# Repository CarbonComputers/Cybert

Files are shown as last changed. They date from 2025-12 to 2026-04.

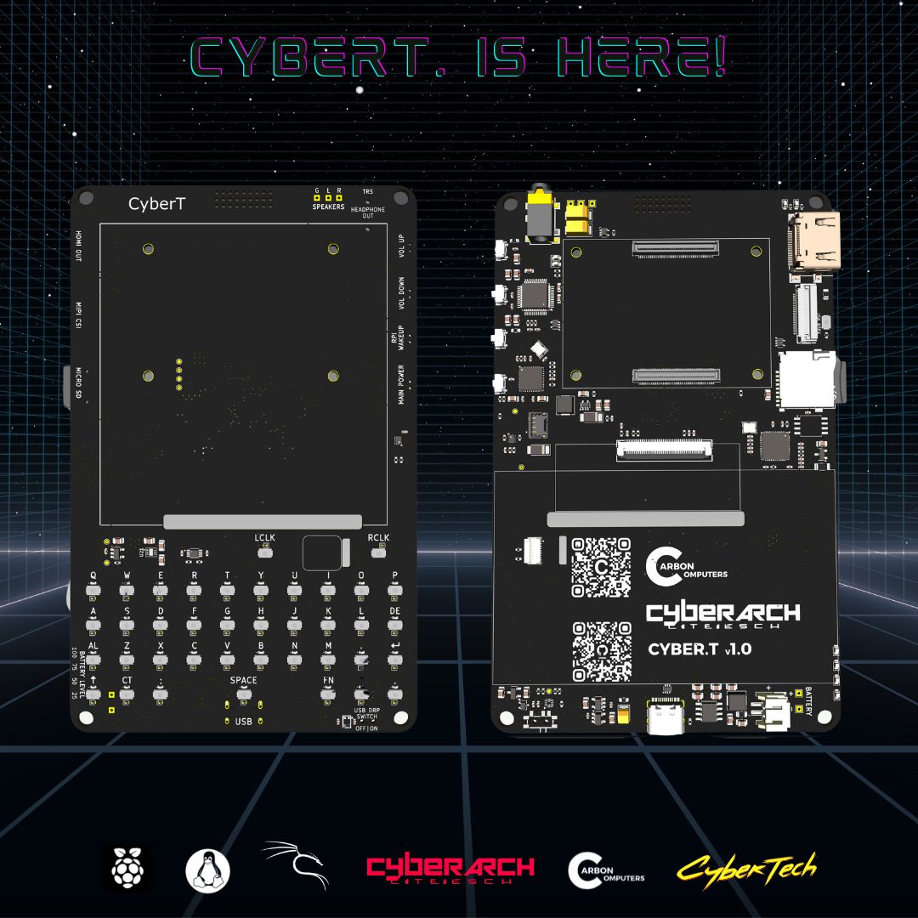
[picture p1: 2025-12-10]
Hardware/Renders/3.jpg

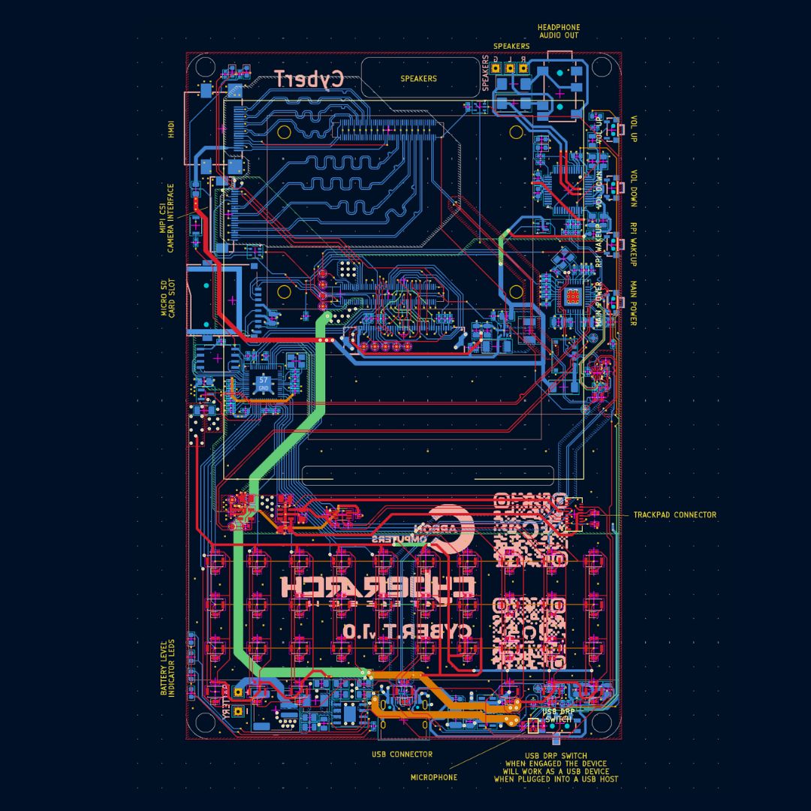
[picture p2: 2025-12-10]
Hardware/Renders/4.jpg

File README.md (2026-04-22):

# Cybert — Raspberry Pi CM5 Handheld Terminal

Order at:
[CarbonComputers.us]
(https://carboncomputers.us/products/cybert-raspberry-pi-cm5-terminal)

Cybert is a compact, modular handheld terminal built around the Raspberry Pi Compute Module 5 (CM5).  
It’s designed for makers, pentesters, IT professionals, students — anyone who needs portable Linux power in a small, customizable footprint.

---

## ⚙️ Features

- **Modular Raspberry Pi CM5 support** — compatible with 4GB, 8GB, or 16GB CM5 boards.  
- **Compact form factor** — optimized for portability while retaining full functionality.  
- **Customizable I/O & expansion** — USB, display, storage, and optional modules (M.2, LoRa, etc.).  
- **Display support** — compatible with TFT/IPS displays (e.g. 3.95" 720×720 or other supported models).  
- **Power & battery** — internal LiPo battery support (varies by configuration).  
- **Active cooler compatible** — supports low-profile cooling solutions for stable performance.  
- **MicroSD / Storage flexibility** — ability to swap OS or storage via microSD, with optional SSD/M.2 expandability.  
- **Open for customization** — intended as a platform for DIY, tinkering, and custom builds.

---

## 📦 What’s Included (Base / Barebones Kit)

Depending on the version you choose, the kit may include:  
- Enclosure (case)  
- Compatible display mount and instructions for supported display  
- Internal wiring/connectors  
- USB port layout & headers  
- Battery compartment and wiring for battery connection  
- PCB / carrier board for CM5 

> ⚠️ Note: If you purchase the *barebones* variant — the CM5 board, storage media, and optional cooler are **not included** and must be provided separately by the user.

---

## 🔧 Recommended Components & Compatibility

| Component | Notes |
|---|---|
| Displays | Compatible with supported TFT/IPS screens (3.95” 720×720 IPS) link (https://www.buydisplay.com/square-3-95-inch-720x720-ips-tft-lcd-display-rgb-interface) |
| Touch Sensor | Blackberry 9900 Bold 4 Trackpad Sensor link (https://www.cellspare.com/blackberry-bold-4-9900-trackpad-sensor-module)
| CM5 Variants | 4 GB, 8 GB, or 16 GB — all supported |
| Cooling | Low-profile passive or active coolers recommended for extended use |
| Storage | MicroSD for OS; M.2/SSD or other modules supported via expansion |
| Power | Use compatible LiPo, check battery compartment size, connect safely, check polarity first Dim 5 x 55 x 70mm (https://a.co/d/gQhkSEN) |
| Power Switch | 3-position slider - Part Number SSSS812201 |

---

## 🛠️ Assembly & Setup

1. Install the Raspberry Pi CM5 (if not included).  
2. Mount the compatible display per display instructions or kit documentation.  
3. Connect power (battery or external as applicable).  
4. Insert microSD (or other storage) with desired OS (Raspberry Pi OS, Ubuntu, Kali, etc.).  
5. Boot the unit — configure OS, display settings, I/O, and peripherals as needed.  
6. If using external modules (M.2, LoRa, etc.), check compatibility and wire appropriately.  

---

## 📝 License & Usage Policy

- Open-source components (e.g. 3D models, firmware) are licensed under [**CERN-OHL-P 2.0** / **Apache 2.0 / MIT**] — see `LICENSE` file for full details.  
- **Manufacturing and commercial distribution is restricted.** The PCB, gerbers, and full hardware build files are licensed under a **non-commercial hardware license**.  
- Personal, educational, and hobbyist builds are permitted.  
- Commercial manufacturing or resale requires a separate licensing agreement from the project maintainers.

---

## 📚 Documentation & Resources

- Assembly guide, wiring diagrams, BOM, and schematics — see `/docs` directory.  
- Display compatibility info — refer to documentation for supported TFT/IPS models.  
- Firmware, scripts, and software tools — available under `/firmware` and `/software`.  
- Example builds, community mods, and contributions — welcome!  

---

## 💡 Contributing & Feedback

Contributions are welcome! Whether you’re improving the 3D model, adding support for new peripherals, or fixing bugs — feel free to submit a pull request or issue.  

Before contributing, please review [CONTRIBUTING.md](CONTRIBUTING.md) for guidelines and license terms.

---

## 📢 Community & Support

For support, questions, or custom licensing requests:  
- Visit our website or product page  
- Email: **info@carboncomputers.us**  
- Follow us on social media for updates and build logs  

---

Thank you for your interest in Cybert. — happy building & hacking 🚀

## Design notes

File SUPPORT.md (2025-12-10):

# Support — Cybert

For help, questions, or issues, you can:

- Open a GitHub issue  
- Join the discussion board on discord (https://discord.gg/W2pCgAYwHk)
- Contact support at **support@carboncomputers.us**
- Call 786 505 3830

Commercial licensing inquiries:
**licensing@carboncomputers.us**

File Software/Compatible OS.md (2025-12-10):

## **Installing Other Operating Systems on the Cybert**

The Cybert supports many operating systems designed for the Raspberry Pi 5 series. However, keep in mind that the Raspberry Pi 5 (BCM2712) is still a relatively new platform, so some OS builds—such as Kali—may not yet offer complete support.

On this page, you’ll find OS-specific folders with instructions on installing the display driver for this screen.
If you want to try an operating system *not* listed, you can follow the general method below.

---

## **General Installation Method**

### **Step 1:**

Download the following files from this page:

* `vc4-kms-dpi-hyperpixel4sq.dtbo`
* `hyperpixel4.dtbo`

### **Step 2:**

Copy both files into the `/overlays/` directory of the OS image.

### **Step 3:**

Add the following lines to `/boot/config.txt`:

```
dtoverlay=vc4-kms-v3d
dtoverlay=vc4-kms-dpi-hyperpixel4sq
```

This installs and activates the display driver.
As long as the OS has basic Pi 5 support, the screen should function correctly.

---

## **Important Note About GPIO Conflicts**

The display uses the default hardware I²C and SPI pins.
Make sure to **disable any OS features or services** that attempt to use those GPIOs to avoid conflicts.

---

## **Fixing Shifted Pixels on the First Column**

Some users may notice a pixel shift on the first column of the display.

To fix this:

### **Step 1:**

Download the file:

* `cybert.dtbo`

### **Step 2:**

Copy it into the `/overlays/` directory of the OS image.

### **Step 3:**

Remove the previous overlay line:

```
dtoverlay=vc4-kms-dpi-hyperpixel4sq
```

Then add:

```
dtoverlay=cybert
```

This will correct the shifted pixel issue.

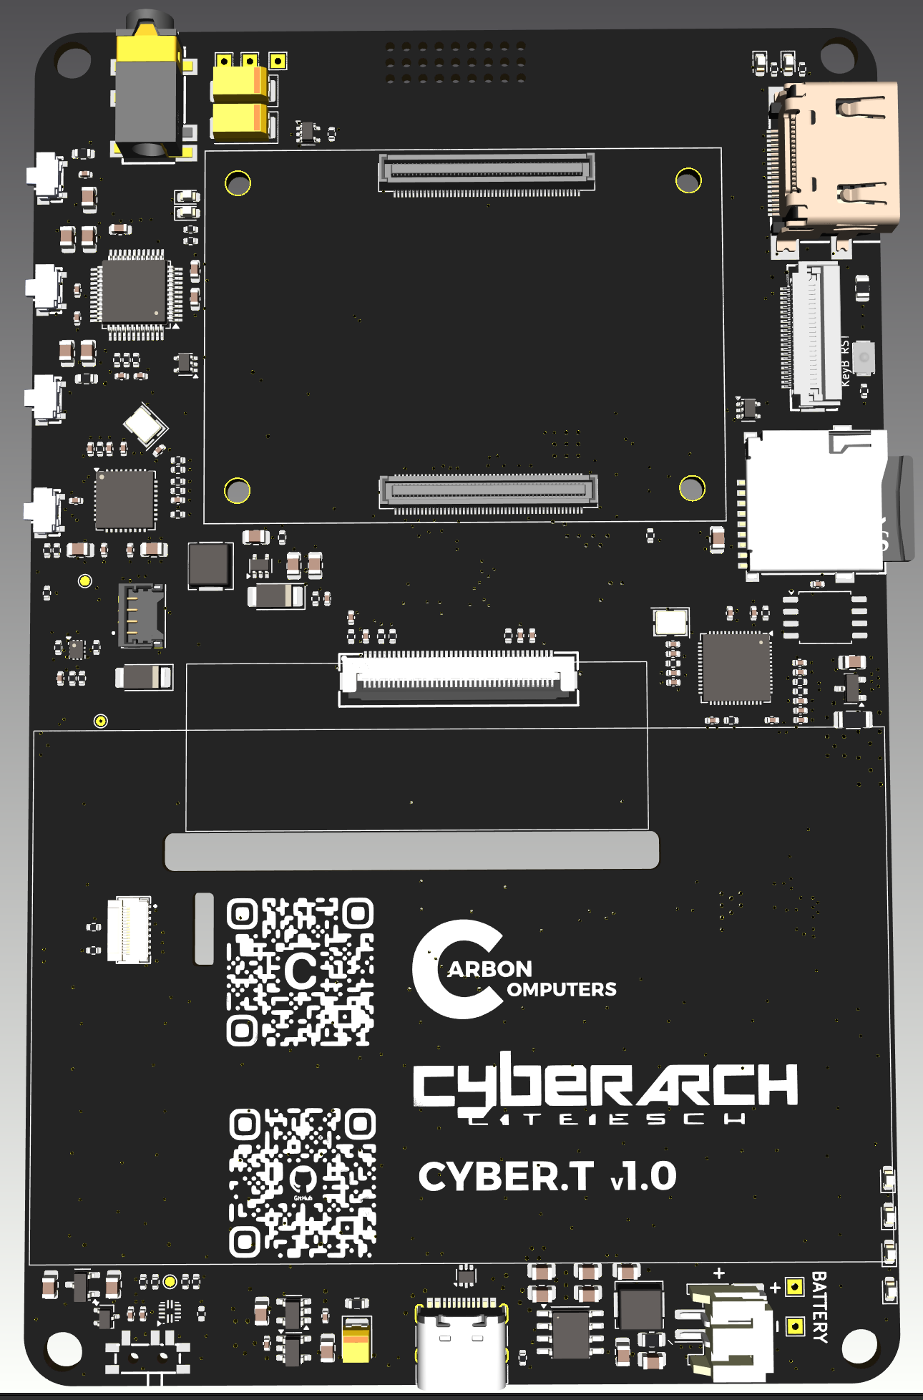
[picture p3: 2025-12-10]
Hardware/Renders/Cybert.png

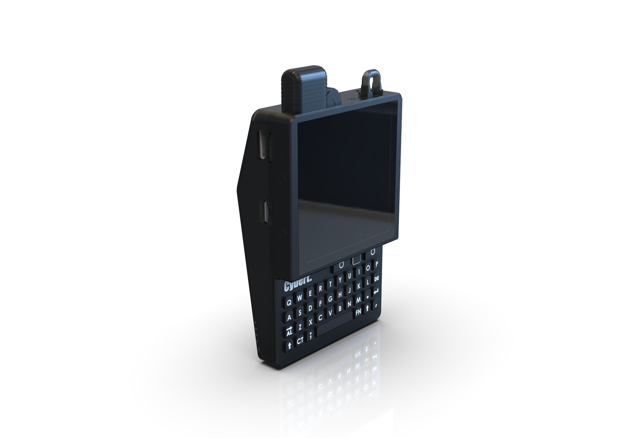
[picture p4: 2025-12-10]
Hardware/Renders/cyberT_HDMI_v2.278.jpg

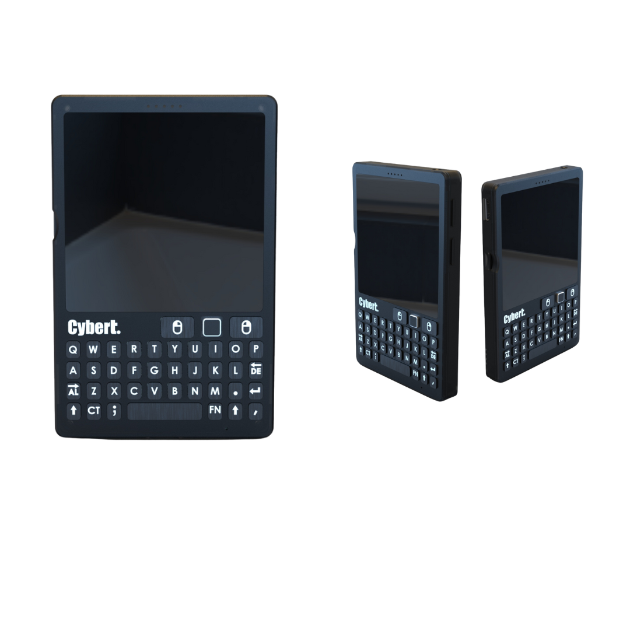
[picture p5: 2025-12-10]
Hardware/Renders/CyberT (7).png

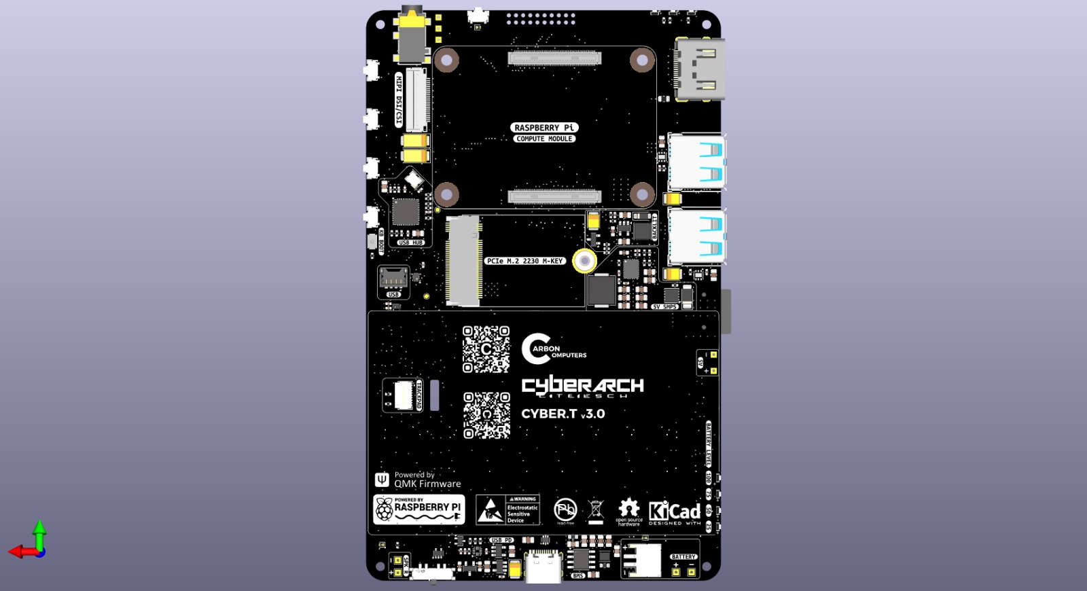
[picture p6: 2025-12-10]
Hardware/Renders/Cybert 3.4..jpeg

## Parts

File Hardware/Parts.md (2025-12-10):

**PCB**
Order at:
[CarbonComputers.us]
(https://carboncomputers.us/products/cybert-raspberry-pi-cm5-terminal)

Compatible Display Model:
[https://www.buydisplay.com/square-3-95-inch-720x720-ips-tft-lcd-display-rgb-interface](https://www.buydisplay.com/square-3-95-inch-720x720-ips-tft-lcd-display-rgb-interface)

**Battery**
Because of the slim enclosure, the maximum recommended size is a **3,000 mAh LiPo**.
Suggested model: **3.7V 3000mAh 505573 LiPo with JST-PH 2.0mm connector**
Dimensions: **5 × 55 × 73 mm**

**Compute Module**
Supports Raspberry Pi CM5 in:

* 4GB
* 8GB
* 16GB

**Cooling**
Compatible with low-profile **active coolers** designed for the Raspberry Pi CM5.

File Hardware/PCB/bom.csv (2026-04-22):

Designator | Footprint | Quantity | Value | LCSC Part #
C1, C4 | 0402 | 2 | 15pF
C10, C101, C11, C13, C14, C15, C19, C2, C21, C26, C30, C31, C36, C39, C43, C44, C49, C59, C60, C66, C79, C98 | 0805 | 22 | 10uF
C100, C96, C99 | 0402 | 3 | 0.1uF
C102, C23, C25, C3, C33, C40, C42, C47, C5, C51, C56, C57, C6, C61, C69, C7, C70, C72, C73, C74, C75, C76, C77, C78, C8, C81, C82, C86, C88, C9 | 0402 | 30 | 0.1uF
C103, C104, C37, C38, C45, C46, C50, C52, C53, C62, C63, C65, C83, C84, C85, C91, C93 | 0805 | 17 | 22uF
C105, C27, C28, C29, C80 | 0603 | 5 | 4.7uF
C12, C97 | CP_EIA-3528-21_Kemet-B | 2 | 100uF
C16, C17 | CP_EIA-6032-28_Kemet-C | 2 | 470uF
C18, C20 | 0402 | 2 | 100pF
C22, C32 | 0402 | 2 | 22pF
C24, C41, C71 | 0402 | 3 | 100nF
C309, C312 | 0805 | 2 | 10uF | CL21A106KBYQNNE
C310 | 0603 | 1 | 2.2uF
C311 | 0402 | 1 | 220pF
C34, C35 | 0402 | 2 | 33pF
C48, C58 | CP_EIA-3528-21_Kemet-B | 2 | 100uF
C64 | 0603 | 1 | 0.1uF
C67, C68 | 0402 | 2 | 1uF
C87 | 0603 | 1 | 2.2uF
C90 | 0402 | 1 | 8.2nF
C92 | 0402 | 1 | 1nF
C94 | 0402 | 1 | 47pF
C95 | 0402 | 1 | 1uF
D1, D11, D12, D13, D14, D15, D16, D17, D18, D20, D21, D22, D25, D26, D27, D30, D31, D32, D33, D35, D36, D37, D40, D41, D42, D43, D45, D46, D47, D48, D50, D51, D52, D53, D6, D7, D77, D8, D81, D9 | D_SOD-882D | 40 | D | BAS16L,315
D10 | D_SOD-128 | 1 | PMEG4030EP,115
D19 | LED-SMD_XL-1606 | 1 | LD1
D2 | D_SOD-123 | 1 | PMEG2010ER,115
D23 | LED-SMD_XL-1606 | 1 | LD2
D24 | LED-SMD_XL-1606 | 1 | LD3
D28 | LED-SMD_XL-1606 | 1 | LD4
D29, D34, D38, D39, D44, D49, D54, D55, D56, D57, D58, D59, D60, D61, D62, D63, D64, D65, D66, D67, D68, D69, D70, D71, D72, D73, D74, D76, D78, D79, D80, D82, D83, D84, D85, D86, D87 | 0402 | 37 | LED
D3 | LED-SMD_XL-1606 | 1 | Pi ACT
D4 | LED-SMD_XL-1606 | 1 | RPI PWR
D75 | SOT-323_SC-70 | 1 | BAT54CW
D88 | LED-SMD_XL-1606 | 1 | PCIe ACT
D89 | D_SOD-128 | 1 | PMEG4050EP
F1 | 0805 | 1 | 200mA
H5 | MountingHole_2.7mm_M2.5_DIN965_Pad_TopBottom | 1 | KEY
J1 | TestPoint_THTPad_1.5x1.5mm_Drill0.7mm | 1 | SPK_L
J10 | TestPoint_THTPad_1.5x1.5mm_Drill0.7mm | 1 | BAT+
J11 | AUDIO-SMD_PJ-3420-A-SMT_C319102 | 1 | HEADPHONE
J12 | TestPoint_THTPad_1.5x1.5mm_Drill0.7mm | 1 | BAT-
J13 | USB_C_Receptacle_HRO_TYPE-C-31-M-12 | 1 | TYPE C
J14 | FPC-SMD_17P-P0.60_HRS_FH35C-17S-0.3SHW | 1 | FH35C-17S-0.3SHW(50)
J15, J16 | REF | 2 | CM5
J17 | PCI-APCI0079-P002A | 1 | Bus_M.2_Socket_M
J18, J19 | U-A-39DS-Y-1 | 2 | U-A-39DS-Y-1
J2 | HDMI_A_Molex_208658-1001_Horizontal | 1 | HDMI_A_1.4 | HC-HDMI0019T-4
J20 | REF | 1 | display
J21, J4 | TestPoint_THTPad_1.5x1.5mm_Drill0.7mm | 2 | SPK_R
J22, J6 | TestPoint_THTPad_1.5x1.5mm_Drill0.7mm | 2 | SPK_GND
J23 | TestPoint_THTPad_1.5x1.5mm_Drill0.7mm | 1 | +5V
J24 | TestPoint_THTPad_1.5x1.5mm_Drill0.7mm | 1 | GND
J3 | FFC-SMD_22P-P0.50_X05A20L22T | 1 | CSI 1 | X05A20L22T
J5 | TF-SMD_TF-01A | 1 | Micro_SD_Card | TF-01A
J7 | MOLEX_0781710004 | 1 | USB
J8 | JST_PH_S2B-PH-SM4-TB_1x02-1MP_P2.00mm_Horizontal | 1 | BATTERY
J9 | AFC07-S40ECA-00 | 1 | AFC07-S40ECA-00
L1 | 0603 | 1 | BLM18BD252SN1
L2 | L_Sunlord_SWPA252012S | 1 | 1uH
L3, L5 | L_Sunlord_MWSA0618S | 2 | MWSA0618S-2R2MT
L30 | L_Sunlord_SWPA4010S | 1 | SWPA4012S100MT
L4 | L_Sunlord_MWSA0624S | 1 | MWSA0624S-1R0MT
L9 | 0805 | 1 | PSBHAA201210H-681T040 | C85824
Q1 | Diodes_PowerDI3333-8 | 1 | DMP3013SFV
Q2, Q3 | SOT-23 | 2 | AO3400A
R1 | 0603 | 1 | 2R
R10, R11, R13, R15 | 0402 | 4 | 36k
R12 | 0402 | 1 | 12k
R14, R7 | 0402 | 2 | 0R
R16, R17, R43, R45 | 0402 | 4 | 22R
R18, R19, R3, R4, R52 | 0402 | 5 | 1k
R2, R21, R24, R25, R28, R29, R30, R33, R35, R44, R46, R50, R51 | 0402 | 13 | 10k
R20 | 0402 | 1 | 10.5k
R22, R9 | 0402 | 2 | 100k
R23 | 0402 | 1 | 1.5k
R26, R27, R53 | 0402 | 3 | 100k
R31, R38 | 0402 | 2 | 15k
R32, R49 | 0402 | 2 | 220R
R34 | 1206 | 1 | 10R
R36 | 0603 | 1 | 0.5R
R39, R40 | 0402 | 2 | 5.1k
R41, R6 | 0402 | 2 | 33.2k
R42 | 0402 | 1 | 0R
R5 | 0402 | 1 | 120k
R56 | 0402 | 1 | 267k
R57 | 0402 | 1 | 113k
R58 | 0402 | 1 | 23.7k
R59 | 0402 | 1 | 220k
R60 | 0402 | 1 | 69.8k
R8 | 0402 | 1 | 10k
SW1 | KEY-SMD_TX-1010-X-X | 1 | PI WAKEUP
SW10, SW11, SW12, SW13, SW14, SW15, SW16, SW18, SW19, SW20, SW22, SW23, SW24, SW25, SW26, SW28, SW29, SW30, SW31, SW33, SW34, SW35, SW38, SW39, SW4, SW40, SW41, SW43, SW44, SW45, SW46, SW48, SW49, SW5, SW50, SW51, SW6, SW7, SW9 | SW_TS18-5-25-SL-260-SMT-TR | 39 | TS18
SW17 | KEY-SMD_TX-1010-X-X | 1 | POWER
SW2 | SW_SPST_CK_KXT3 | 1 | RESET
SW21 | KEY-SMD_TX-1010-X-X | 1 | DISPLAY BACKLIGHT
SW27 | SSSS812201 | 1 | SSSS812201
SW3 | KEY-SMD_TX-1010-X-X | 1 | VOL DWN
SW8 | KEY-SMD_TX-1010-X-X | 1 | VOL UP
TP11, TP5 | TestPoint_Pad_D1.0mm | 2 | nEXTRST
TP12 | TestPoint_Pad_D1.0mm | 1 | nPiBOOT
U1, U15 | SOT-23-6 | 2 | TPS565208DDCR
U10 | SOT-666 | 1 | USBLC6-2P6
U12, U13 | WDFN-6_L2.0-W2.0-P0.65-BL-EP-1 | 2 | AP2553FDC-7
U16, U5 | UQFN-10_1.4x1.8mm_P0.4mm | 2 | TS3USB30ERSWR
U17 | QFN-56-1EP_7x7mm_P0.4mm_EP3.2x3.2mm | 1 | RP2040
U18 | HTSOP-8-1EP_3.9x4.9mm_P1.27mm_EP2.4x3.2mm | 1 | IP5306
U19 | SOIC-8_5.3x5.3mm_P1.27mm | 1 | W25Q128JVS
U2 | X2SON-8_1.4x1mm_P0.35mm | 1 | TXS0102DQE
U21 | LLP-6_L2.0-W1.8-P0.50-BL-EP | 1 | VRD1828MLX
U22 | IC_TPS61088RHLR | 1 | TPS61088RHLR
U23 | SOT-23-3 | 1 | XC6206PxxxMR
U25 | Texas_X2QFN-12_1.6x1.6mm_P0.4mm | 1 | FUSB303BTMX | C895444
U26 | SOT-23-5 | 1 | AP22814AW5
U27 | SOT-23-5 | 1 | AP22814BW5
U3 | QFN-36-1EP_6x6mm_P0.5mm_EP3.7x3.7mm_ThermalVias | 1 | USB2514B_Bi
U57 | SOT-23-5 | 1 | LMR62014XMFX
U6 | Raspberry-Pi-5-Compute-Module | 1 | RPi-CM5
U7 | SOT-353_SC-70-5 | 1 | SN74LVC1G07DCKR
U8 | MIC-SMD_4P-L2.8-W1.9_S15OT421-005 | 1 | S15OT421-005
U9 | LQFP-48_7x7mm_P0.5mm | 1 | CM108
Y1 | Crystal_SMD_Abracon_ABM8G-4Pin_3.2x2.5mm | 1 | 24MHz | C156248
Y2 | Crystal_SMD_SeikoEpson_FA238-4Pin_3.2x2.5mm | 1 | 12MHz
Y3 | Oscillator_SMD_SiT_PQFN-4Pin_3.2x2.5mm | 1 | OK2JI-111-32.768K

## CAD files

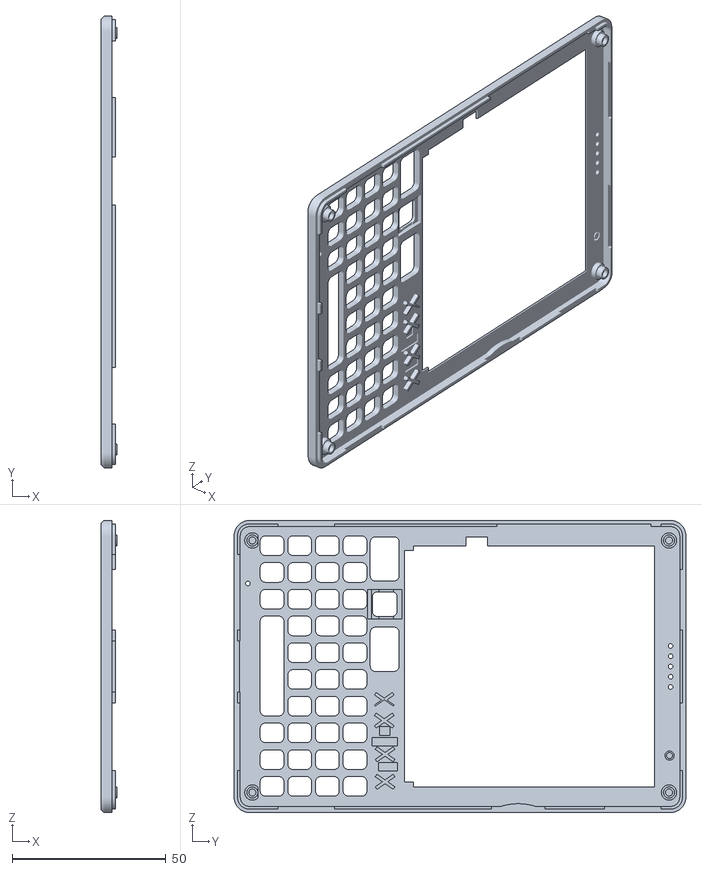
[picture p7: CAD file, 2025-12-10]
Hardware/3D Model/Cybert._slim_v3_rev4_STP_STL_DXF/front_panel_v3_rev4.stl
5.30 x 147.0 x 95.0

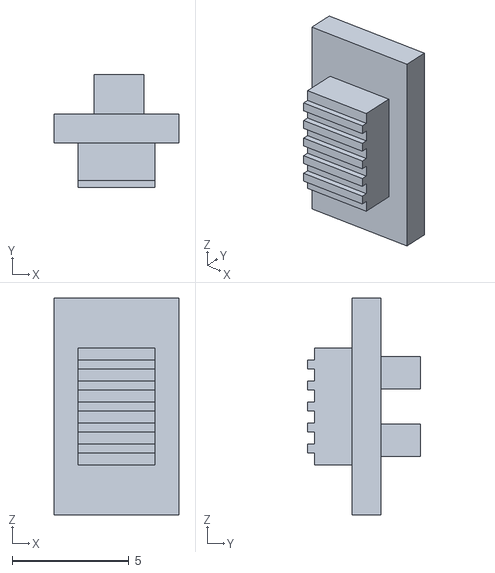
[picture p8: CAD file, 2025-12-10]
Hardware/3D Model/cyberT_case_HDMI_v2_rev1_STL/sliding_switch_v2.stl
5.35 x 4.83 x 9.30

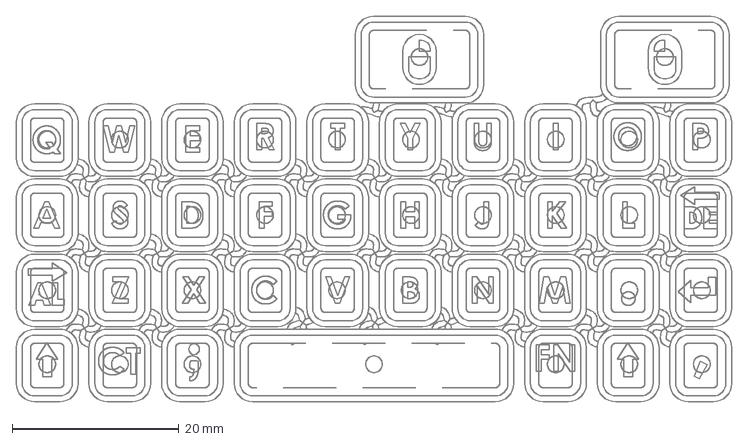
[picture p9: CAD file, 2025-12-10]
Hardware/3D Model/Cybert._slim_v3_rev4_STP_STL_DXF/keyboard_v3_rev2.dxf
85.7 x 46.2 mm

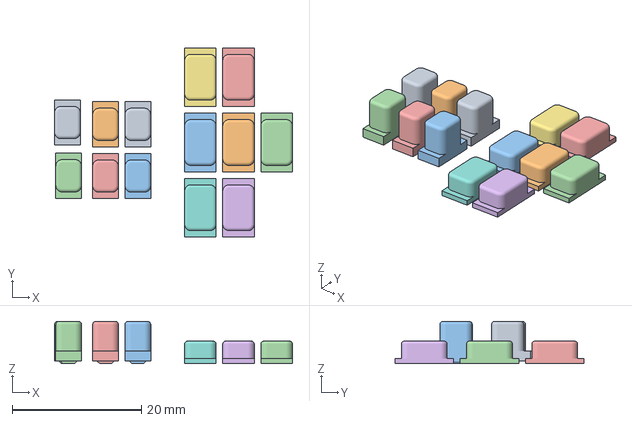
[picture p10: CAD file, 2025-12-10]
Hardware/3D Model/cyberT_case_HDMI_v2_rev1_STL/display_button_v2.3mf
36.8 x 29.3 x 6.54 mm
display_button_v2.stl x 6
side_button_v1.stl x 7

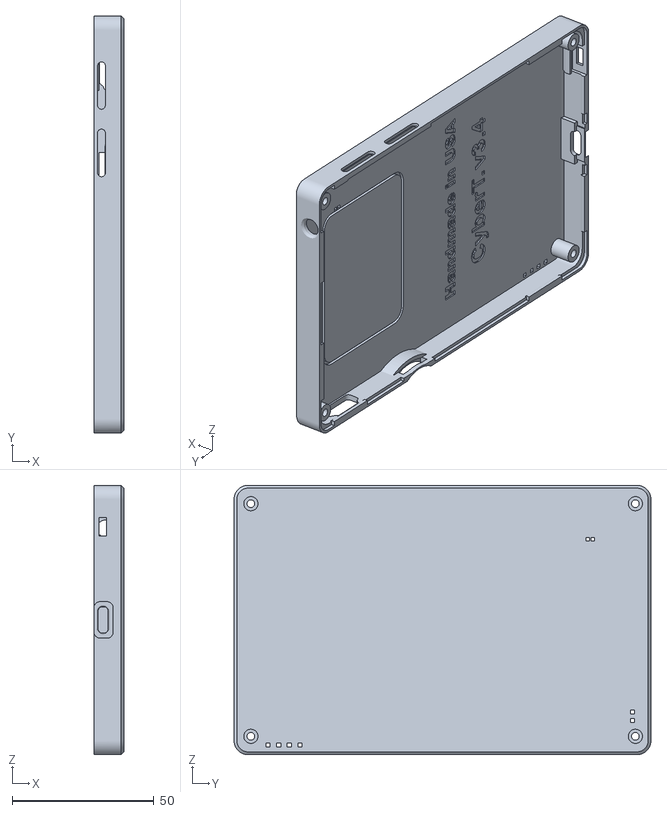
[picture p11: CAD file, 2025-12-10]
Hardware/3D Model/Cybert._slim_v3_rev4_STP_STL_DXF/back_panel_v3_rev4.stl
10.6 x 147.0 x 95.0

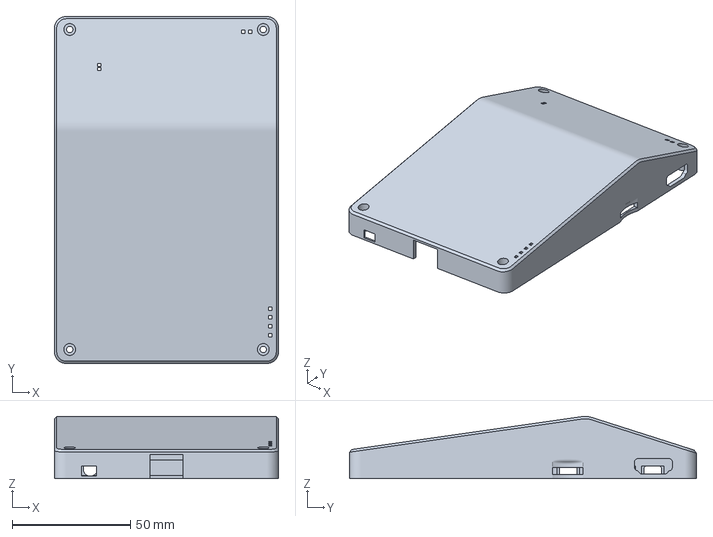
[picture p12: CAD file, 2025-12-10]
Hardware/3D Model/cyberT_case_HDMI_v2_rev1_STL/back_panel_v2_rev1.3mf
95.0 x 147.0 x 26.3 mm

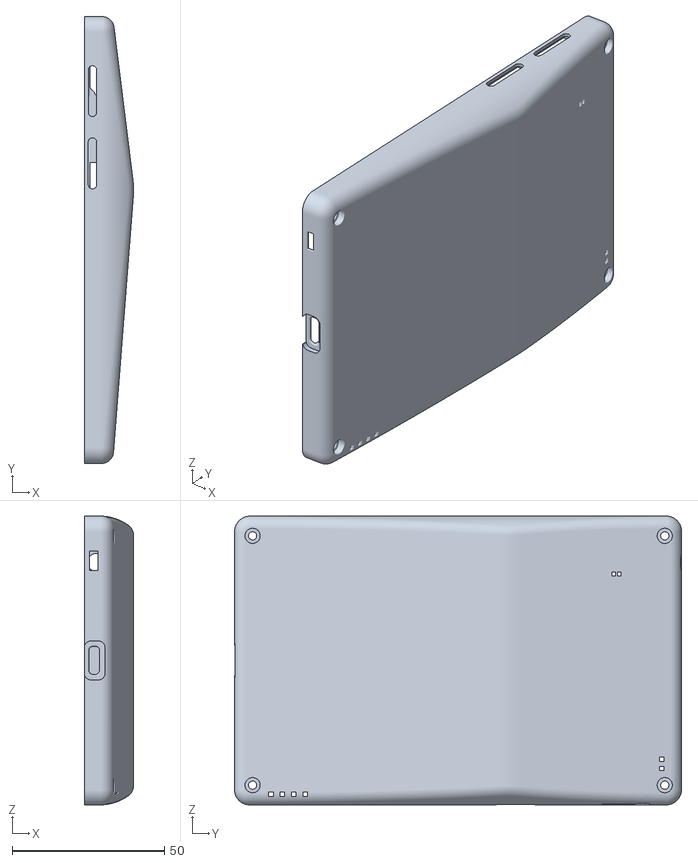
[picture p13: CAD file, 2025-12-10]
Hardware/3D Model/Cybert._slim_v3_rev4_STP_STL_DXF/Angle back_panel_v4.stl
16.2 x 147.0 x 95.0

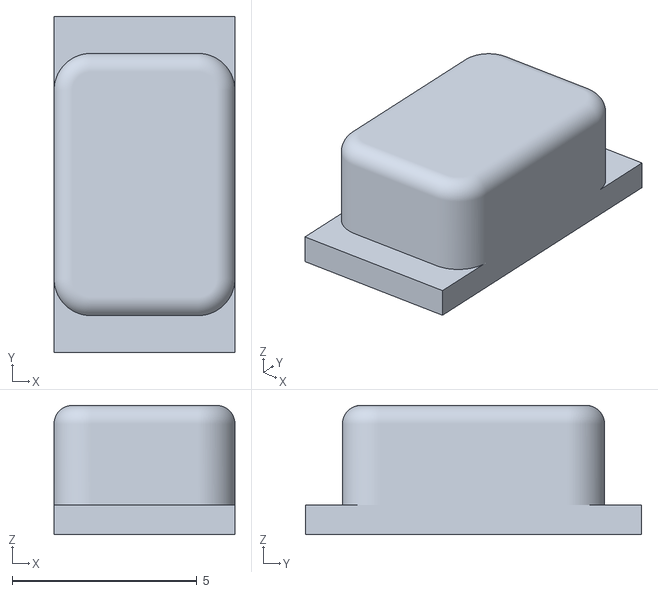
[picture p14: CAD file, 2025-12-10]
Hardware/3D Model/cyberT_case_HDMI_v2_rev1_STL/side_button_v1.stl
4.90 x 9.10 x 3.50

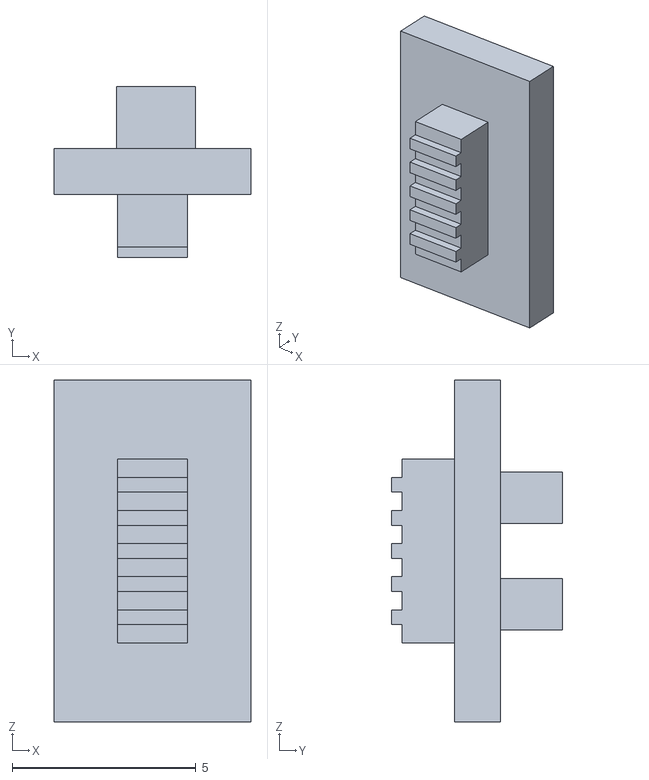
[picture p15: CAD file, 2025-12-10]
Hardware/3D Model/Cybert._slim_v3_rev4_STP_STL_DXF/sliding_switch_v3_rev1.stl
5.35 x 4.64 x 9.30

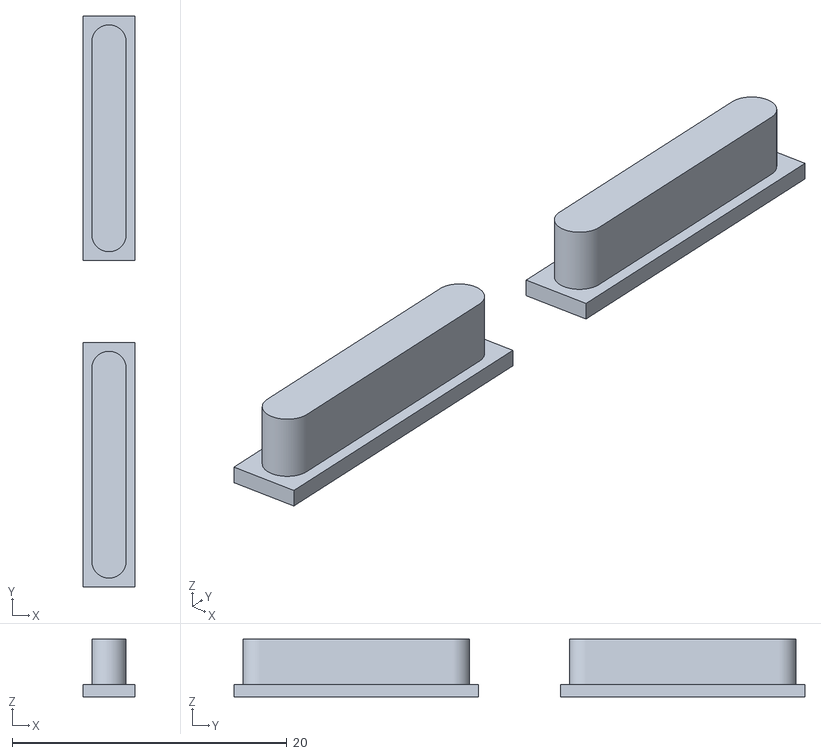
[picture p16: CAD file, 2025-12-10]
Hardware/3D Model/Cybert._slim_v3_rev4_STP_STL_DXF/side_button_v3_rev1.stl
3.80 x 41.6 x 4.20

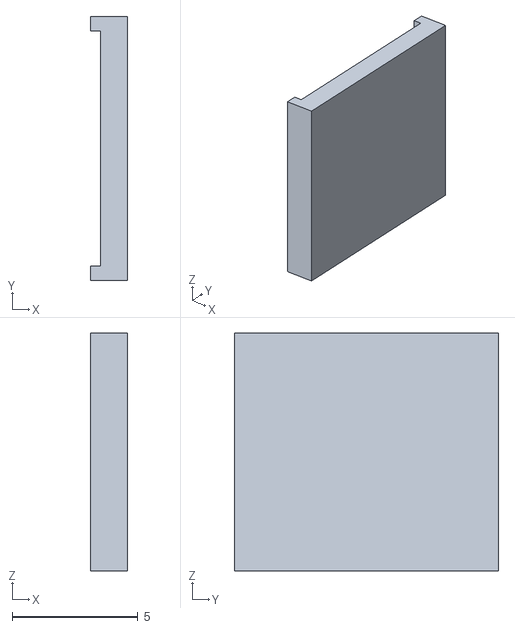
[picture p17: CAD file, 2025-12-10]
Hardware/3D Model/Cybert._slim_v3_rev4_STP_STL_DXF/sensor_spacer_v1.stl
1.47 x 10.5 x 9.45

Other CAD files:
Hardware/3D Model/cyberT_case_HDMI_v2_rev1_STL/back_panel_v2_rev1.stl
Hardware/3D Model/cyberT_case_HDMI_v2_rev1_STL/display_button_v2.stl

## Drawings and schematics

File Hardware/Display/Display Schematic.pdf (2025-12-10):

720x720

# 3.95 inch

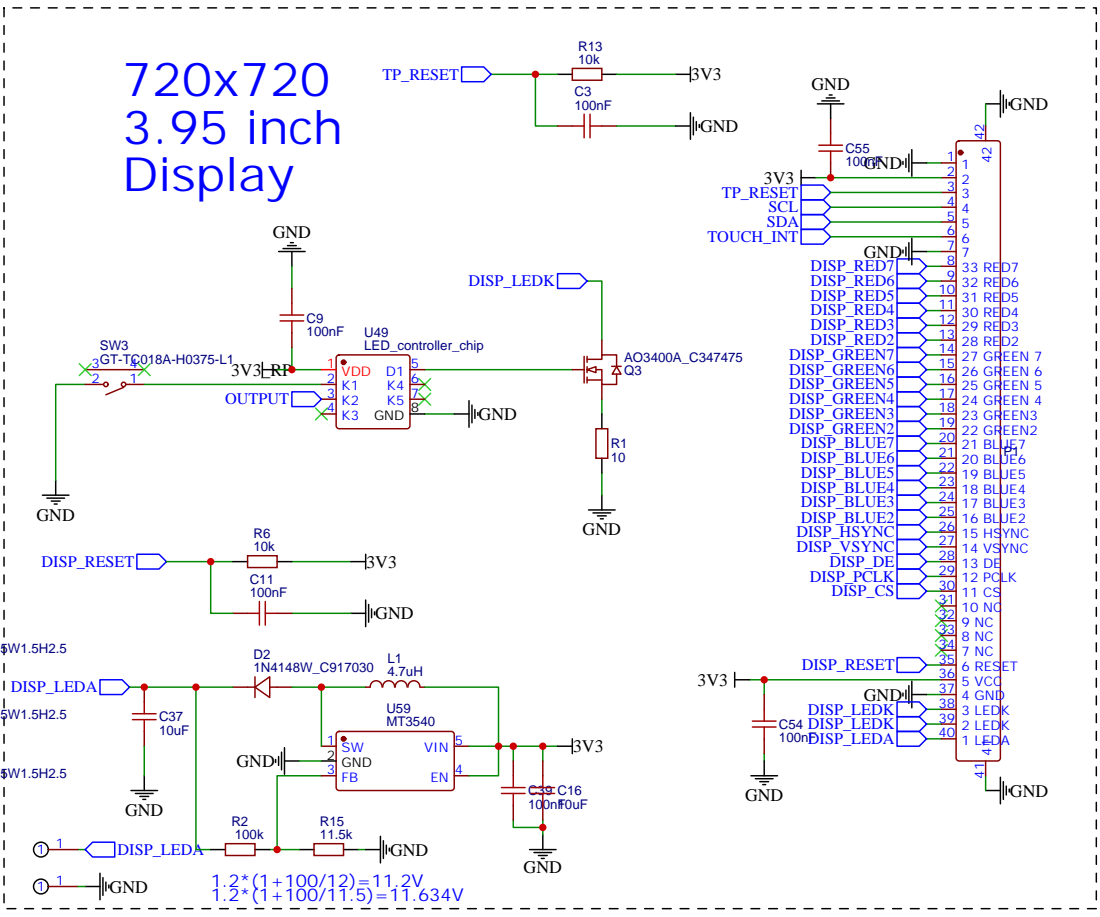
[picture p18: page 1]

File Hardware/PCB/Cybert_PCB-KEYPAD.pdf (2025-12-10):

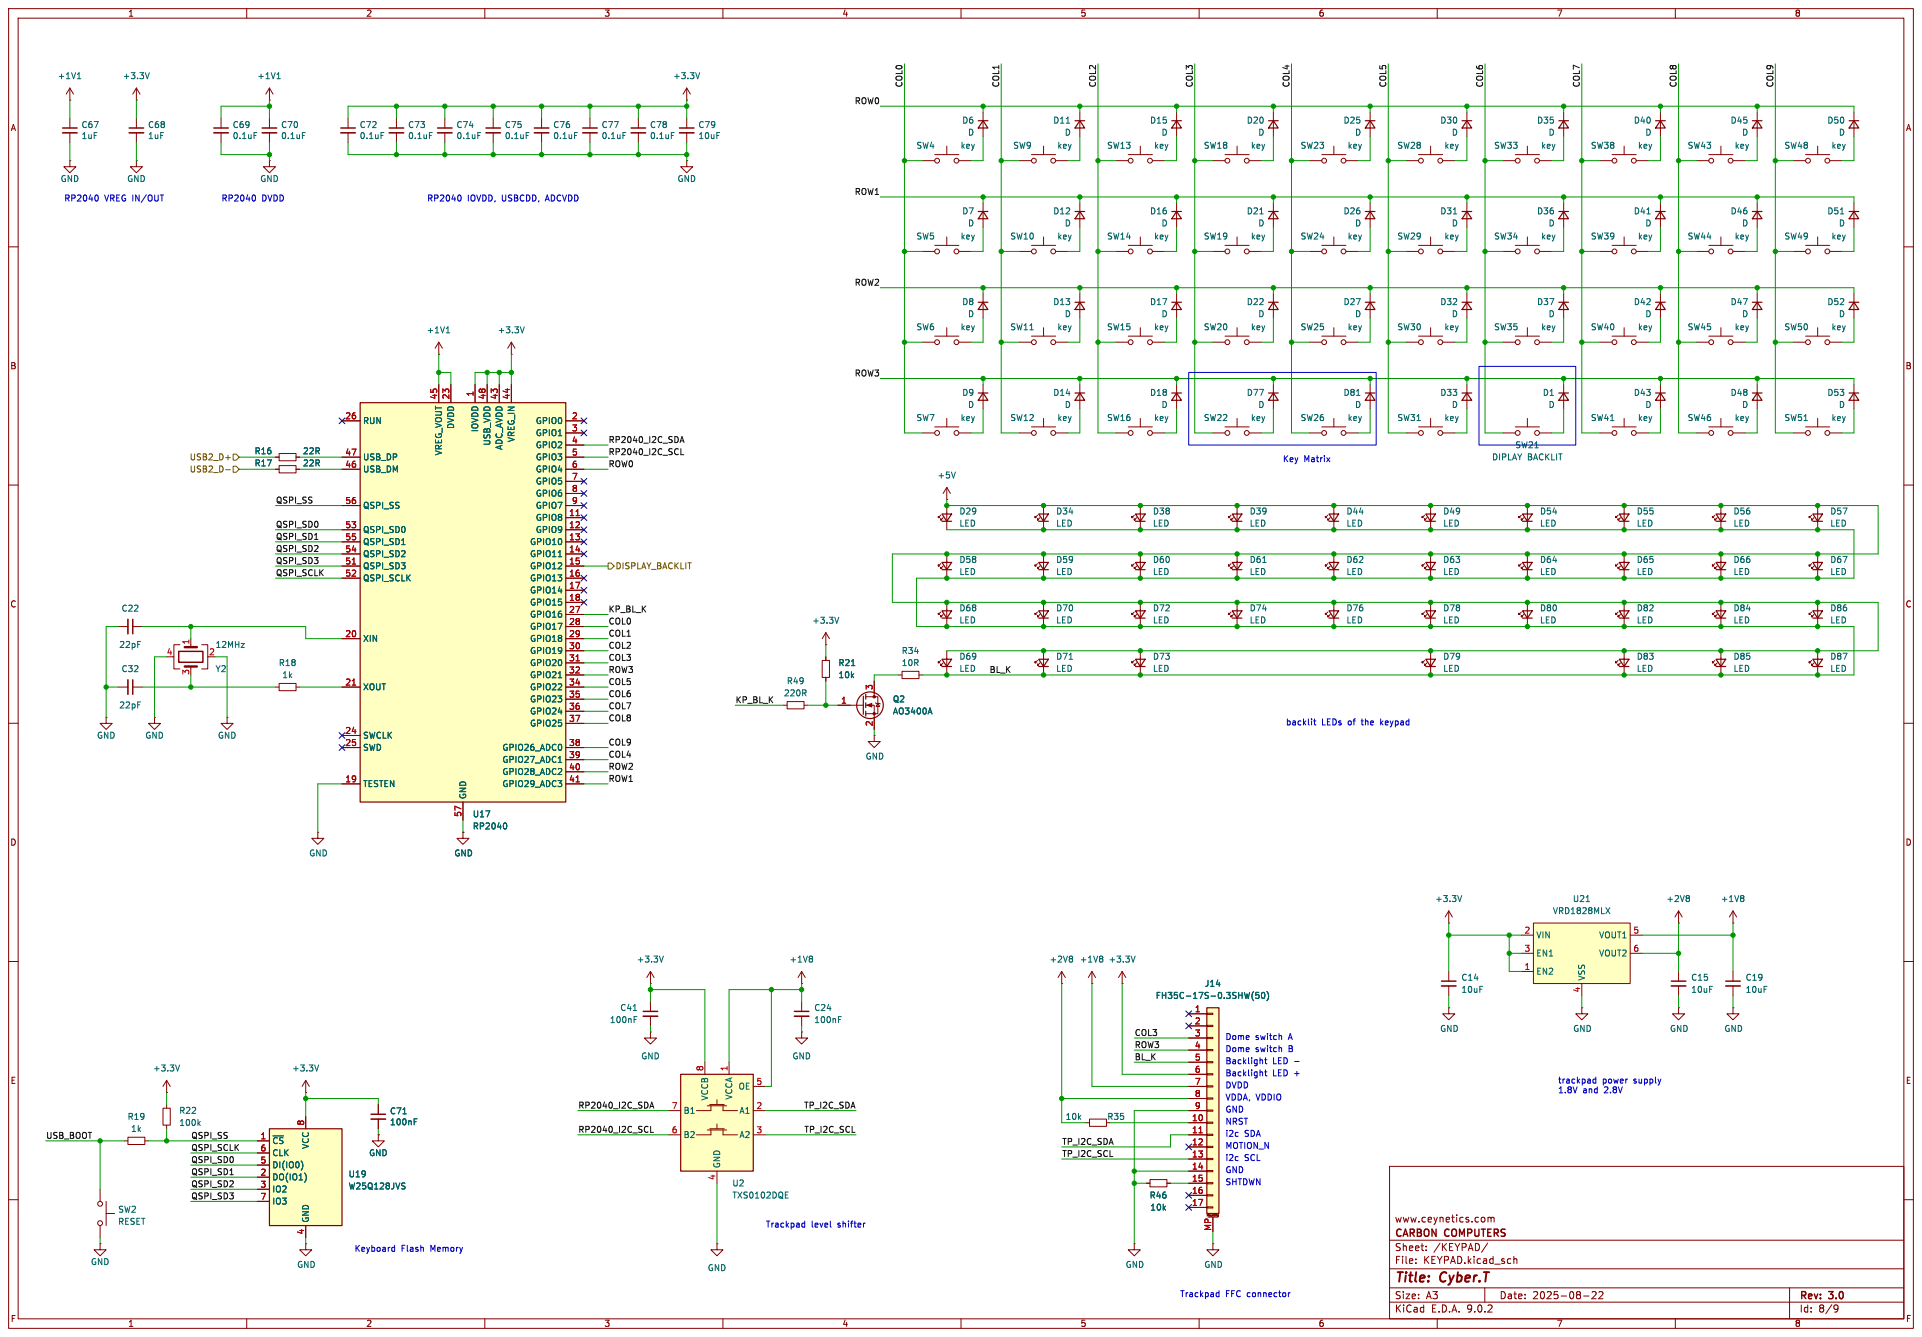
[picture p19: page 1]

~{CS} 1 CLK 6 DI(IO0) 5 DO(IO1) 2

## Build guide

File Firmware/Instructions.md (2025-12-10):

To flash the firmware, connect the **bottom USB-C port** of the Cybert to your computer. After a moment, a new storage device named **“RP2040”** should appear.

Drag and drop the `.uf2` firmware file onto that drive. The RP2040 will automatically reboot and flash the firmware. Keep it connected for about 5 seconds to complete the process.

Once finished, test the keyboard and touchpad—moving your finger on the touchpad should move the cursor on your computer.

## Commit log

2025-12-10 inital commit
    [Angle back_panel_v4.stl, back_panel_v2_rev1.3mf, back_panel_v2_rev1.stl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]
2026-04-22 Add files via upload
    Cybert BOM
    [bom.csv]
